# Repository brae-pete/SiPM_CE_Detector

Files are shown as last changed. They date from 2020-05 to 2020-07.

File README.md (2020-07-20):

# SiPM Fluorescence Detector
Open Source Fluorescence Detector thas was applied for Capillary Electrophoresis. We noticed there was very little performance difference between the SiPM and the PMT when used in an epi-illumination setup. 

Included here is the KiCAD project folder, gerber files for PCB fabrication, STL files for 3D printed detector housing, list of materials for the circuit, an example electropherogram, and a jupyter notebook highlighting the data analysis. The project file 'Redraw' can be opened to view the circuit schematic. There are 2 PCB layout files, one for the 3 mm and one for the 6 mm sensor.

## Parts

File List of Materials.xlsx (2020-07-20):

Qty | Reference(s) | Value | Notes/Material | Size | Approximate Cost (USD) | Part #
1 | C1 | 10nF | Ceramic | 0805 (2012 Metric) | 0.1 | 885342207014
1 | C2 | 22p | Ceramic | 0603 (1608 Metric) | 0.3 | C0603C220K5RACAUTO
3 | C3, C6, C10 | 0.1uF | Ceramic | 1206 (3216 Metric) | 0.63 | 12061C104KAT2A
2 | C4, C5 | 10uF | Electrolytic | 4x3.9 | 1 | UZR1C100MCL1GB
1 | C7 | 200n | Ceramic | 0603 (1608 Metric) | 0.17 | CC0603KPX7R8BB224
4 | C8, C9, C12, C13 | 1uF | Tantalum | 1206 (3216 Metric) | 1.2 | F921V105MAA
2 | C11, C14 | 10uF | Ceramic | 1206 (3216 Metric) | 2.04 | C1206X106K3RACTU
1 | D1 | SiPM | Silicon Photomultiplier |  | 52.69 | MICROFC-30050-SMT-TR1
3 | D2, D3, D4 | D | General Purpose | SOD-123-F2 | 0.3 | BAS16GWJ
1 | J1 | BNC Coaxial Conn. | Jack Right Angle | Through Hole | 3.79 | 5227161-3
1 | J2, J3, J4 | -48V, +6, -6 V input | Screw Terminal Block | 5.08 mm Pitch | 1.56 | TB007-508-02BE
1 | R1 | 470 | Thin Film | 0608 (1608 Metric) | 0.6 | CPF0603B470RE1
1 | R2 | 50 | Thick Film | 1206 (3216 Metric) | 0.1 | CRCW120649R9FKEAC
1 | R3, RV1 | RTRIM (10k) | Bourns | 3269W_Vertical | 9.66 | 3269W-1-103LF
1 | R4 | 240 | Thin Film | 3216 (1206 Metric) | 0.19 | RT1206FRE07240RL
1 | R5 | 700 | Thin Film | 3216 (1206 Metric) | 0.67 | 667-ERA-8AEB6980V
2 | R6, R8 | 210 | Thin Film | 3216 (1206 Metric) | 0.36 | RT1206FRE07210RL
1 | R7 | 670 | Thin Film | 3216 (1206 Metric) | 0.67 | ERA-8AEB6650V
1 | U1 | AD8675 | Op-amp | SOIC-8 | 3.26 | AD8675ARZ
2 | U2, U4 | LM337L_SO8 | Voltage Regulator | SOIC-8 | 1.82 | LM337LM/NOPB
1 | U3 | LM317_3PinPackage | Voltage Regulator | SOT-223 | 0.87 | LM317MQDCYR
1 | -48V | >36 V DC Power Supply >0.5 A | Power Supply | AC/DC Adapter | 13.73 | GST25B48-P1J
2 | +6V, -6V | >6 V DC Power Supply >1 A | Power Supply | AC/DC Adapter (12V) | 19.74 | XYY-120300E
 |  |  |  | Total Cost | 115.45

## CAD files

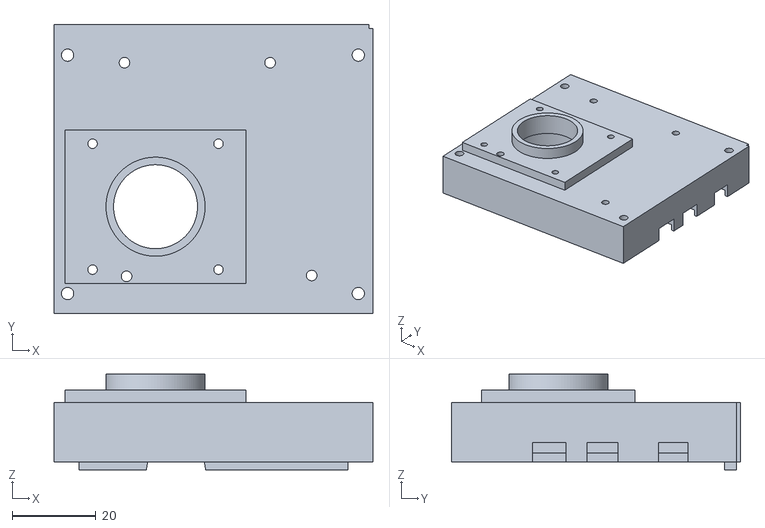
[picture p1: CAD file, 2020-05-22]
SiPM Mount/Bottom_Mount.stl
76.0 x 68.8 x 22.8

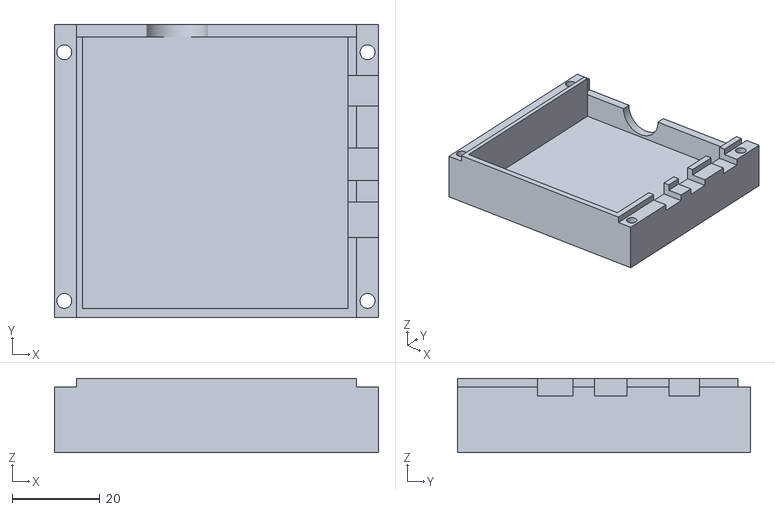
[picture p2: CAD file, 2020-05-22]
SiPM Mount/Upper+Cover.stl
74.0 x 66.8 x 17.0

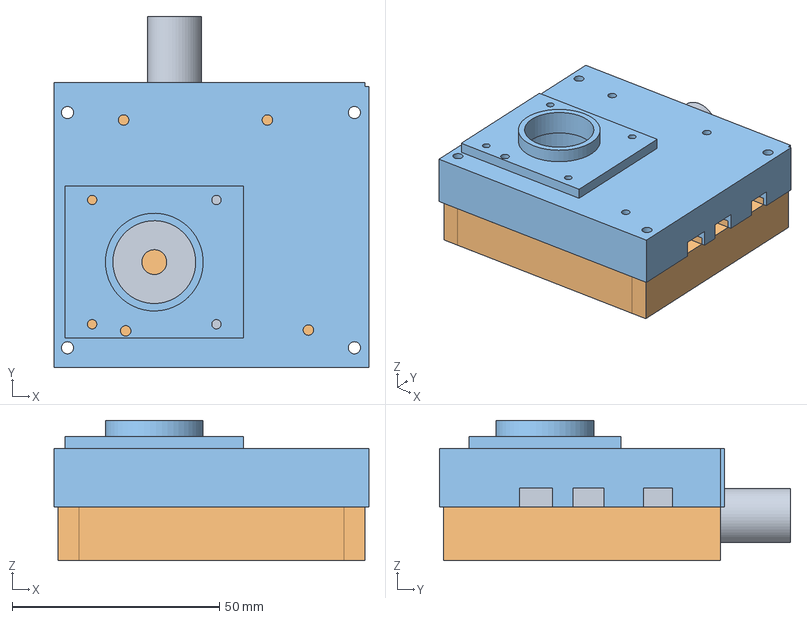
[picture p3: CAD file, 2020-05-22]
SiPM Mount/SiPM Mount v6.step
76.0 x 84.7 x 33.8 mm

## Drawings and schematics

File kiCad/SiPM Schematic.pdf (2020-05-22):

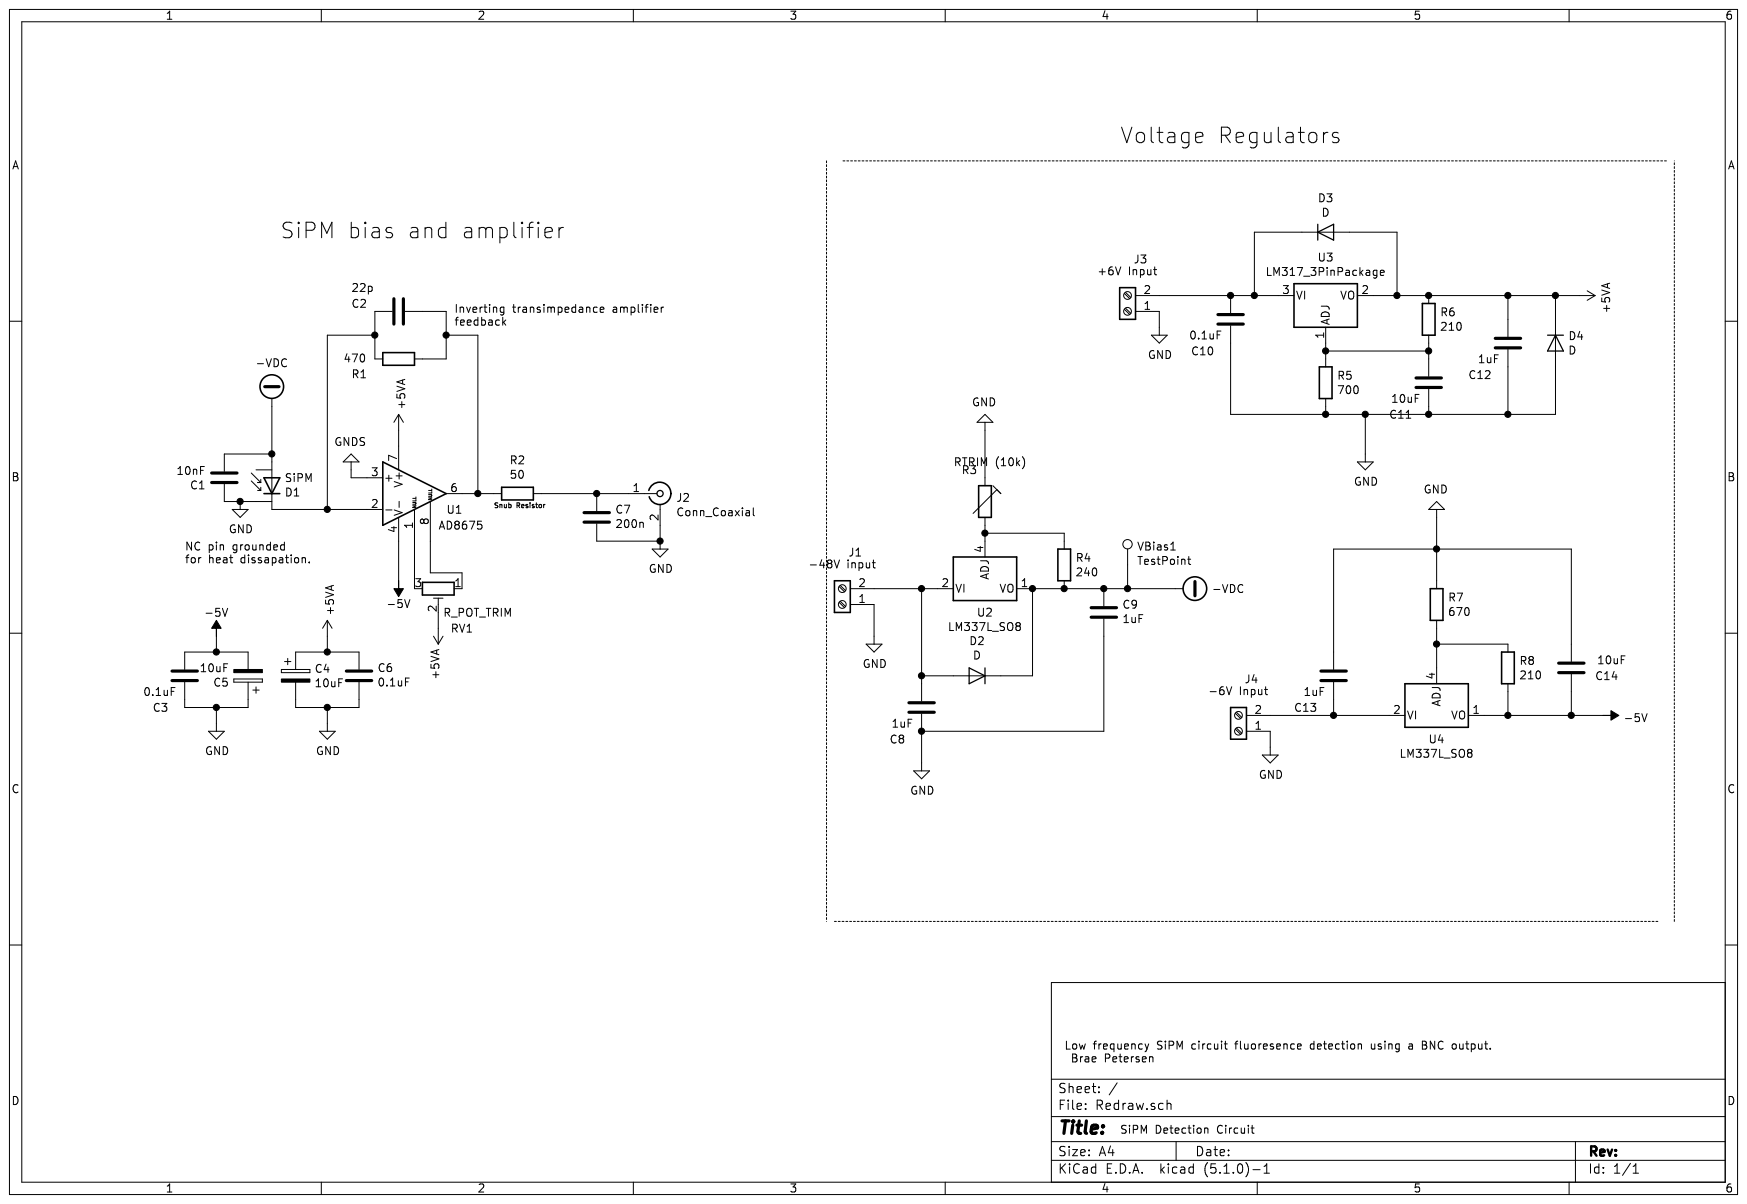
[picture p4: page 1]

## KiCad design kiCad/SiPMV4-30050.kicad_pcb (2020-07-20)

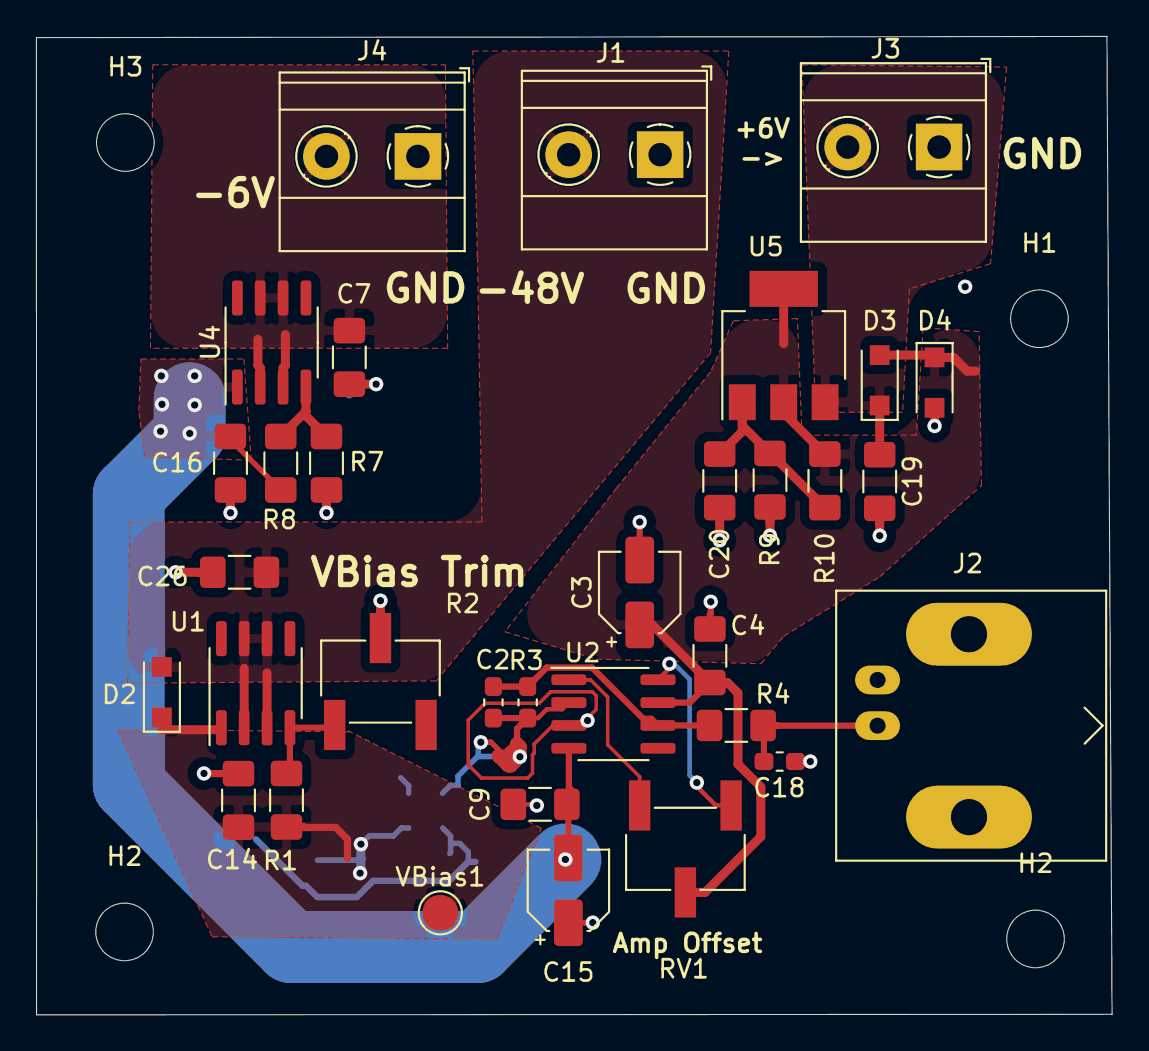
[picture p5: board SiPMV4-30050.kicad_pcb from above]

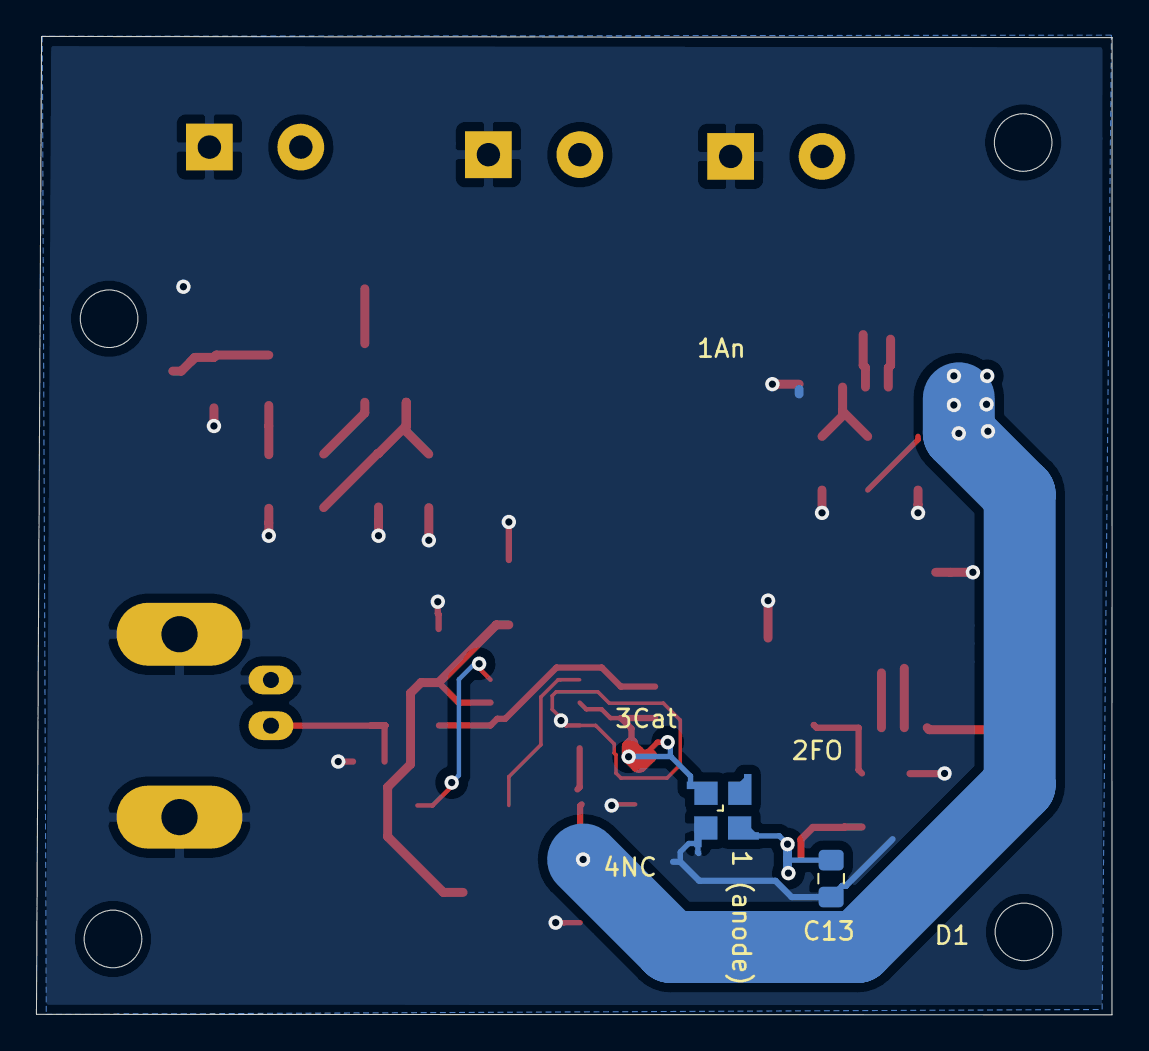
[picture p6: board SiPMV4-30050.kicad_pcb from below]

Board: 2 copper layers, 59.8 x 54.4 mm, 39 parts (2 on the bottom side), 15 nets.

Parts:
C2: 22p; C_0603_1608Metric_Pad1.05x0.95mm_HandSolder
C3, C15: 10uF; CP_Elec_4x3.9
C4, C9, C19: 0.1uF; C_1206_3216Metric_Pad1.42x1.75mm_HandSolder
C7, C14, C26: 1uF; C_1206_3216Metric_Pad1.42x1.75mm_HandSolder
C13: 10nF; C_0805_2012Metric_Pad1.15x1.40mm_HandSolder
C16, C20: 10uF; C_1206_3216Metric_Pad1.42x1.75mm_HandSolder
C18: 200n; C_0603_1608Metric_Pad1.05x0.95mm_HandSolder
D1: SiPM; Microfc_30050
D2, D3, D4: D; D_SOD-123F
H1, H2, H2#2, H3: MountingHole; MountingHole_3.2mm_M3
J1, J3, J4: Screw_Terminal_01x02; TerminalBlock_Phoenix_MKDS-1,5-2-5.08_1x02_P5.08mm_Horizont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
J2: Conn_Coaxial; BNC_Amphenol_B6252HB-NPP3G-50_Horizontal
R1: 240; R_1206_3216Metric_Pad1.42x1.75mm_HandSolder
R2: RTRIM (10k); Potentiometer_Bourns_3269W_Vertical
R3: 470; R_0603_1608Metric_Pad1.05x0.95mm_HandSolder
R4: 50; R_1206_3216Metric_Pad1.42x1.75mm_HandSolder
R7: 670; R_1206_3216Metric_Pad1.42x1.75mm_HandSolder
R8, R10: 210; R_1206_3216Metric_Pad1.42x1.75mm_HandSolder
R9: 700; R_1206_3216Metric_Pad1.42x1.75mm_HandSolder
RV1: R_POT_TRIM; Potentiometer_Bourns_3269W_Vertical
U1, U4: LM337L_SO8; SOIC-8_3.9x4.9mm_P1.27mm
U2: AD8675; SOIC-8_3.9x4.9mm_P1.27mm
U5: LM317_3PinPackage; SOT-223
VBias1: TestPoint; TestPoint_Pad_D2.0mm

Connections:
+5VA: C3.1, C4.2, D3.2, D4.1, R10.1, RV1.2, U2.7, U5.2, U5.4
+6V: C19.1, D3.1, J3.2, U5.3
+48V: C26.1, D2.2, J1.2, U1.2, U1.3, U1.6, U1.7
-5V: C9.1, C15.2, C16.2, R8.2, U2.4, U4.1
-6V: C7.2, J4.2, U4.2, U4.3, U4.6, U4.7
FB1: C2.2, R3.1, R4.1, U2.6
GND: C3.2, C4.1, C7.1, C9.2, C13.2, C14.1, C15.1, C16.1, C18.2, C19.2, C20.2, C26.2, D1.4, D4.2, J1.1, J2.2, J3.1, J4.1, R2.2, R7.1, R9.2, U2.3
unnamed: C2.1, D1.3, R3.2, U2.2
unnamed: C13.1, C14.2, D1.1, D2.1, R1.1, U1.1, U1.8, VBias1.1
unnamed: C18.1, J2.1, R4.2
unnamed: C20.1, R9.1, R10.2, U5.1
unnamed: R1.2, R2.1, U1.4
unnamed: R7.2, R8.1, U4.4
unnamed: RV1.1, U2.8
unnamed: RV1.3, U2.1

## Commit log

2020-05-22 KiCad Files
2020-05-22 Gerber Files
    [SiPMV4-30050-B_Cu.gbr, SiPMV4-30050-B_Mask.gbr, SiPMV4-30050-B_SilkS.gbr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]
2020-05-22 CAD Files
    [Bottom_Mount.stl, SiPM Mount v6.step, Upper+Cover.stl]
2020-05-22 Digital Filter Workflow
    [Example_Electropherogram.xlsx]
2020-07-20 List of Materials
    [List of Materials.xlsx]
2020-07-20 Image
    Image of the circuit.
